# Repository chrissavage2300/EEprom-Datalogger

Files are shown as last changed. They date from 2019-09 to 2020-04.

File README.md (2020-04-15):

The purpose of this project is to take in readings from various sensors (Light and Temperature) and store them in a EEprom. I re-started this project because I wanted to log temperature and the amount of light in a particular area for a garden. I wanted it to be small and not be a full fledged datalogger with a transmitter.

Features:
* Capacitor Backup that will last at the very least 12 hours (During the night)
* Solar charging during the day
* Integrated ORing power circuit so it will charge the capacitor and run the supporting circuitry
* According to my calculations, for a whole year of 1 reading per hour every day I will need about 8kb of memory per sensor. ADC readings iwll be 8 bits each. In practice there's no need for a 10 bit ADC.
* 32kHz Clock run from Timer 1 for accurate timing
* Why Supercapacitor? Temperature range pretty much. Lithium's only go down to 0C and often times temperatures dip below that. Supercapacitors have a range of -40C to 60C which covers the range of outdoor temperatures. 
* Ive integrated a set of UART commands to feedback the status of the micro. It will always take data, there is no stop.
* Upgraded the caps from 3F to 2x6F for a total of 12F. This should last about 27 hours at 370uA consumption. I never could figure out where that is all going, but its not the micro. It only takes 2-3 minutes to charge in full sun though. So even if its cloudy or the sun panel isnt efficient enough, it only needs a few minutes to charge fully. 
* Note: When sending UART commands a "1" has to come before it, so "1a" to read the EEprom. This is by design to wake up the micro so it can recieve stuff properly.
* The Micro Keeps track of the current EEprom address. One issue is that if power ever does get low enough, it will lose the current EEprom address and therefore return to 0 and then all data will be lost. I could have dumped in the EEprom address into the micro's own EEprom and store it if power gets low, but I chose not to.

Commands are as follows:
* "1a" = Read EEprom
* "1E" = Erase EEprom
* "1q" = Status, spits out Seconds,Minutes,MaxAddress,Temp,Solar in that order
* "1t" = current time in MM:SS. Does not track hours passed. 
* "1m" = Used Memory Locations. Shows how much memory has been written to. Currently, two bytes get written into the EEprom

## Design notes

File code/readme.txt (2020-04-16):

I2C_EEProm_Datalogger_2020_04_16_A is the latest file

Changes:
4/16/2020-Added in total run time.

4/15/2020- Final Version.Ready for depolyment. 

4/11/2020-RX needs to be tied high in order to avoid triggering The recieve Interrupt

1/26/2020- Temperature Sensor Works. Units are °C

1/19/2020-Board works and turns RB 7 on and off

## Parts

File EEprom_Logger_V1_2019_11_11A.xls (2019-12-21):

"Part" | "Value" | "Device" | "Package"
"C1" | "10pF" | "CAP1206" | "1206" | ‎311-1150-1-ND‎ (https://www.digikey.com/product-detail/en/CC1206JRNPO9BN100/311-1150-1-ND/303060/?itemSeq=309446462)
"C2" | "10pf" | "CAP1206" | "1206" | ‎311-1150-1-ND‎ (https://www.digikey.com/product-detail/en/CC1206JRNPO9BN100/311-1150-1-ND/303060/?itemSeq=309446462)
"C3" | "22uF" | "CAP1206" | "1206" | ‎587-3397-1-ND‎ (https://www.digikey.com/product-detail/en/JMK316ABJ226KL-T/587-3397-1-ND/4157510/?itemSeq=309446346)
"C4" | "22uF" | "CAP1206" | "1206" | ‎587-3397-1-ND‎ (https://www.digikey.com/product-detail/en/JMK316ABJ226KL-T/587-3397-1-ND/4157510/?itemSeq=309446346)
"C5" | "3F | 2.7V" | "CPOL-USE3.5-8" | 283-4197-ND‎ (https://www.digikey.com/product-detail/en/HV0820-2R7305-R/283-4197-ND/3878077/?itemSeq=304842971)
"C6" | "3F | 2.7V" | "CPOL-USE3.5-8" | 283-4197-ND‎ (https://www.digikey.com/product-detail/en/HV0820-2R7305-R/283-4197-ND/3878077/?itemSeq=304842971)
"D1" | LM4040BIM3-2.0/NOPBCT-ND | "V-REFERENCESMD" | "SOT23-3" | ‎LM4040BIM3X-2.5/NOPBCT-ND‎ (https://www.digikey.com/product-detail/en/LM4040BIM3X-2.5%2FNOPB/LM4040BIM3X-2.5%2FNOPBCT-ND/3527237/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)
"IC1" | " AP2138N-3.3TRG1" | "XC63FPM" | "SOT23" | AP2138N-3.3TRG1DICT-ND‎ (https://www.digikey.com/product-detail/en/AP2138N-3.3TRG1/AP2138N-3.3TRG1DICT-ND/4505282/?itemSeq=304696187)
"IC2" | "PIC18F13K22SOP" | "PIC18F13K22SOP" | "SOP20W" | PIC18LF13K22-I/SO-ND‎ (https://www.digikey.com/product-detail/en/PIC18LF13K22-I%2FSO/PIC18LF13K22-I%2FSO-ND/2125565/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)
"IC3" | "MIC94090" | "MIC94090" | "SC-70" | 576-3484-1-ND‎ (https://www.digikey.com/product-detail/en/MIC94090YC6-TR/576-3484-1-ND/2062481/?itemSeq=309193336)
"IC4" | "MCP1700T-2702E/TT " | "XC63FPM" | "SOT23" | MCP1700T-2702E/TTCT-ND‎ (https://www.digikey.com/product-detail/en/MCP1700T-2702E%2FTT/MCP1700T-2702E%2FTTCT-ND/9642903/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)
"IC5" | "24LC64BSN" | "24LC64BSN" | "SO-08" | ‎24LC64-I/SN-ND‎ (https://www.digikey.com/product-detail/en/24LC64-I%2FSN/24LC64-I%2FSN-ND/273428/?itemSeq=309194840)
"IC6" | "TPS613221ADBVR" | "TPS61322" | "DBV5-L" | 296-50502-1-ND‎ (https://www.digikey.com/product-detail/en/TPS613221ADBVR/296-50502-1-ND/9685641/?itemSeq=304964084)
"IC7" | "LM66100" | "LM66100" | "SC70-6" | 296-53540-6-ND‎ (https://www.digikey.com/product-detail/en/LM66100DCKT/296-53540-6-ND/10273340/?itemSeq=305014552)
"IC8" | "LM66100" | "LM66100" | "SC70-6" | 296-53540-6-ND‎ (https://www.digikey.com/product-detail/en/LM66100DCKT/296-53540-6-ND/10273340/?itemSeq=305014552)
"JP1" | "ICSP" | "M05PTH" | "1X05" | ‎2057-PH1-05-UA-ND‎ (https://www.digikey.com/product-detail/en/PH1-05-UA/2057-PH1-05-UA-ND/9830343/?itemSeq=309668104)
"JP3" | "" | "M02LOCK" | "1X02_LOCK" | ‎S1012EC-02-ND‎ (https://www.digikey.com/product-detail/en/PREC002SAAN-RC/S1012EC-02-ND/2774852/?itemSeq=309668382)
"JP7" | "Vsolar" | "CONN_02POLAR_LOCK" | "MOLEX-1X2_LOCK@1" | ‎A98333-ND‎ (https://www.digikey.com/product-detail/en/282834-2/A98333-ND/1150135/?itemSeq=309668994)
"L1" | "4.7uH" | "INDUCTOR1210" | "1210" | ‎587-1624-1-ND‎ (https://www.digikey.com/product-detail/en/CBC3225T4R7MR/587-1624-1-ND/1008239/?itemSeq=309446164)
"R1" | "1k" | "RESISTOR1206" | "1206" | ‎311-1.00KFRCT-ND‎ (https://www.digikey.com/product-detail/en/RC1206FR-071KL/311-1.00KFRCT-ND/731334/?itemSeq=309259054) | stock
"R2" | "4.7k" | "RESISTOR1206" | "1206" | 311-4.70KFRCT-ND‎ (https://www.digikey.com/product-detail/en/RC1206FR-074K7L/311-4.70KFRCT-ND/731834/?itemSeq=309259149)
"R3" | "4.7k" | "RESISTOR1206" | "1206" | 311-4.70KFRCT-ND‎ (https://www.digikey.com/product-detail/en/RC1206FR-074K7L/311-4.70KFRCT-ND/731834/?itemSeq=309259149)
"R4" | "1k" | "RESISTOR1206" | "1206" | ‎311-1.00KFRCT-ND‎ (https://www.digikey.com/product-detail/en/RC1206FR-071KL/311-1.00KFRCT-ND/731334/?itemSeq=309259054) | stock
"R5" | "TBD" | "RESISTOR1206" | "1206" | ‎311-0.0ERCT-ND‎ (https://www.digikey.com/product-detail/en/RC1206JR-070RL/311-0.0ERCT-ND/732131/?itemSeq=309669297)
"R6" | "TBD" | "RESISTOR1206" | "1206"
"R7" | "TBD" | "RESISTOR1206" | "1206" | ‎311-0.0ERCT-ND‎ (https://www.digikey.com/product-detail/en/RC1206JR-070RL/311-0.0ERCT-ND/732131/?itemSeq=309669297)
"R8" | "TBD" | "RESISTOR1206" | "1206"
"R9" | "50" | "RESISTOR1206" | "1206" | ‎311-51.0FRCT-ND‎ (https://www.digikey.com/product-detail/en/RC1206FR-0751RL/311-51.0FRCT-ND/731920/?itemSeq=309445787)
"R10" | "50" | "RESISTOR1206" | "1206" | ‎311-51.0FRCT-ND‎ (https://www.digikey.com/product-detail/en/RC1206FR-0751RL/311-51.0FRCT-ND/731920/?itemSeq=309445787)
"TS1" | "MCP9700-E/TO" | "MCP9700-E/TO" | "TO-92-AMMO" | ‎MCP9700-E/TO-ND‎ (https://www.digikey.com/product-detail/en/MCP9700-E%2FTO/MCP9700-E%2FTO-ND/1212509/?itemSeq=309195025)
"Y1" | "32kHz" | "CRYSTALTC26V" | "TC26V" | ‎728-1001-ND‎ (https://www.digikey.com/product-detail/en/VT200F-12.5PF20PPM/728-1001-ND/1626716/?itemSeq=309446886) | stock

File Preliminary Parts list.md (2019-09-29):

# EEprom-Datalogger
A remote datalogger that uses an EEprom to store data over time. 
Super Cap:  1572-1771-ND

https://www.ti.com/lit/ds/symlink/tps63031.pdf

http://www.ti.com/product/TPS63031

http://www.ti.com/product/TPS62203

https://www.digikey.com/product-detail/en/richtek-usa-inc/RT6150AGQW/1028-1259-1-ND/4733181

https://www.digikey.com/product-detail/en/texas-instruments/TPS63031DSKR/296-39461-1-ND/5143409

https://electronics.stackexchange.com/questions/240329/using-supercapacitor-as-backup-for-mcu

http://www.ti.com/lit/ug/slva726/slva726.pdf

http://www.ti.com/lit/ds/symlink/tps63020.pdf

 TPS613222ADBVR
 
https://www.digikey.com/product-detail/en/texas-instruments/TPS613222ADBVR/296-50503-1-ND/9685642

http://www.ti.com/lit/ds/symlink/tps61322.pdf

MCP1700T-2702E/TTCT-ND‎
https://www.digikey.com/product-detail/en/MCP1700T-2702E%2fTT/MCP1700T-2702E%2fTTCT-ND/9642903/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

LM66100DCKT

http://www.ti.com/lit/ds/symlink/lm66100.pdf

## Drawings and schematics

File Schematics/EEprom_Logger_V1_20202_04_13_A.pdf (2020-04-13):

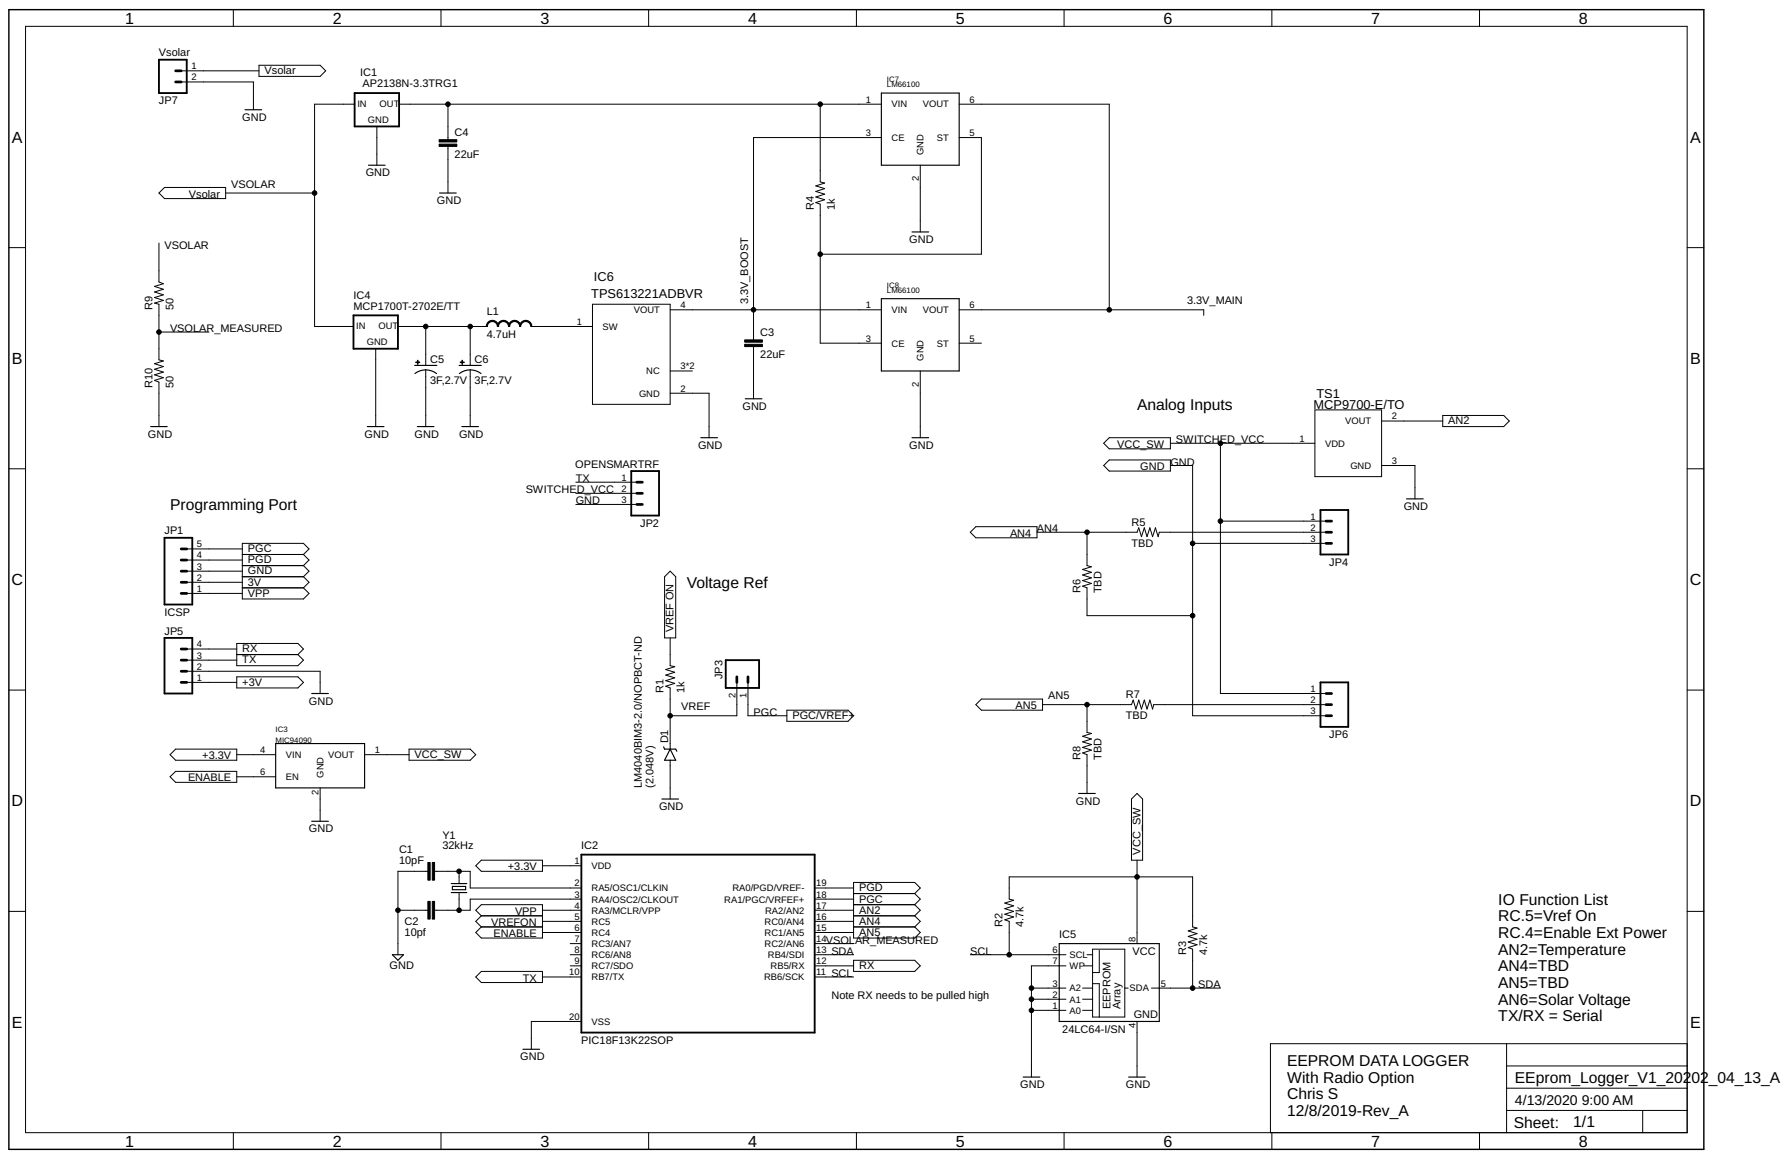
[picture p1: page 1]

IO Function List RC.5=Vref On RC.4=Enable Ext Power AN2=Temperature AN4=TBD

AN6=Solar Voltage TX/RX = Serial Note RX needs to be pulled high

EEPROM DATA LOGGER With Radio Option Chris S 12/8/2019-Rev_A

Sheet: 1/1

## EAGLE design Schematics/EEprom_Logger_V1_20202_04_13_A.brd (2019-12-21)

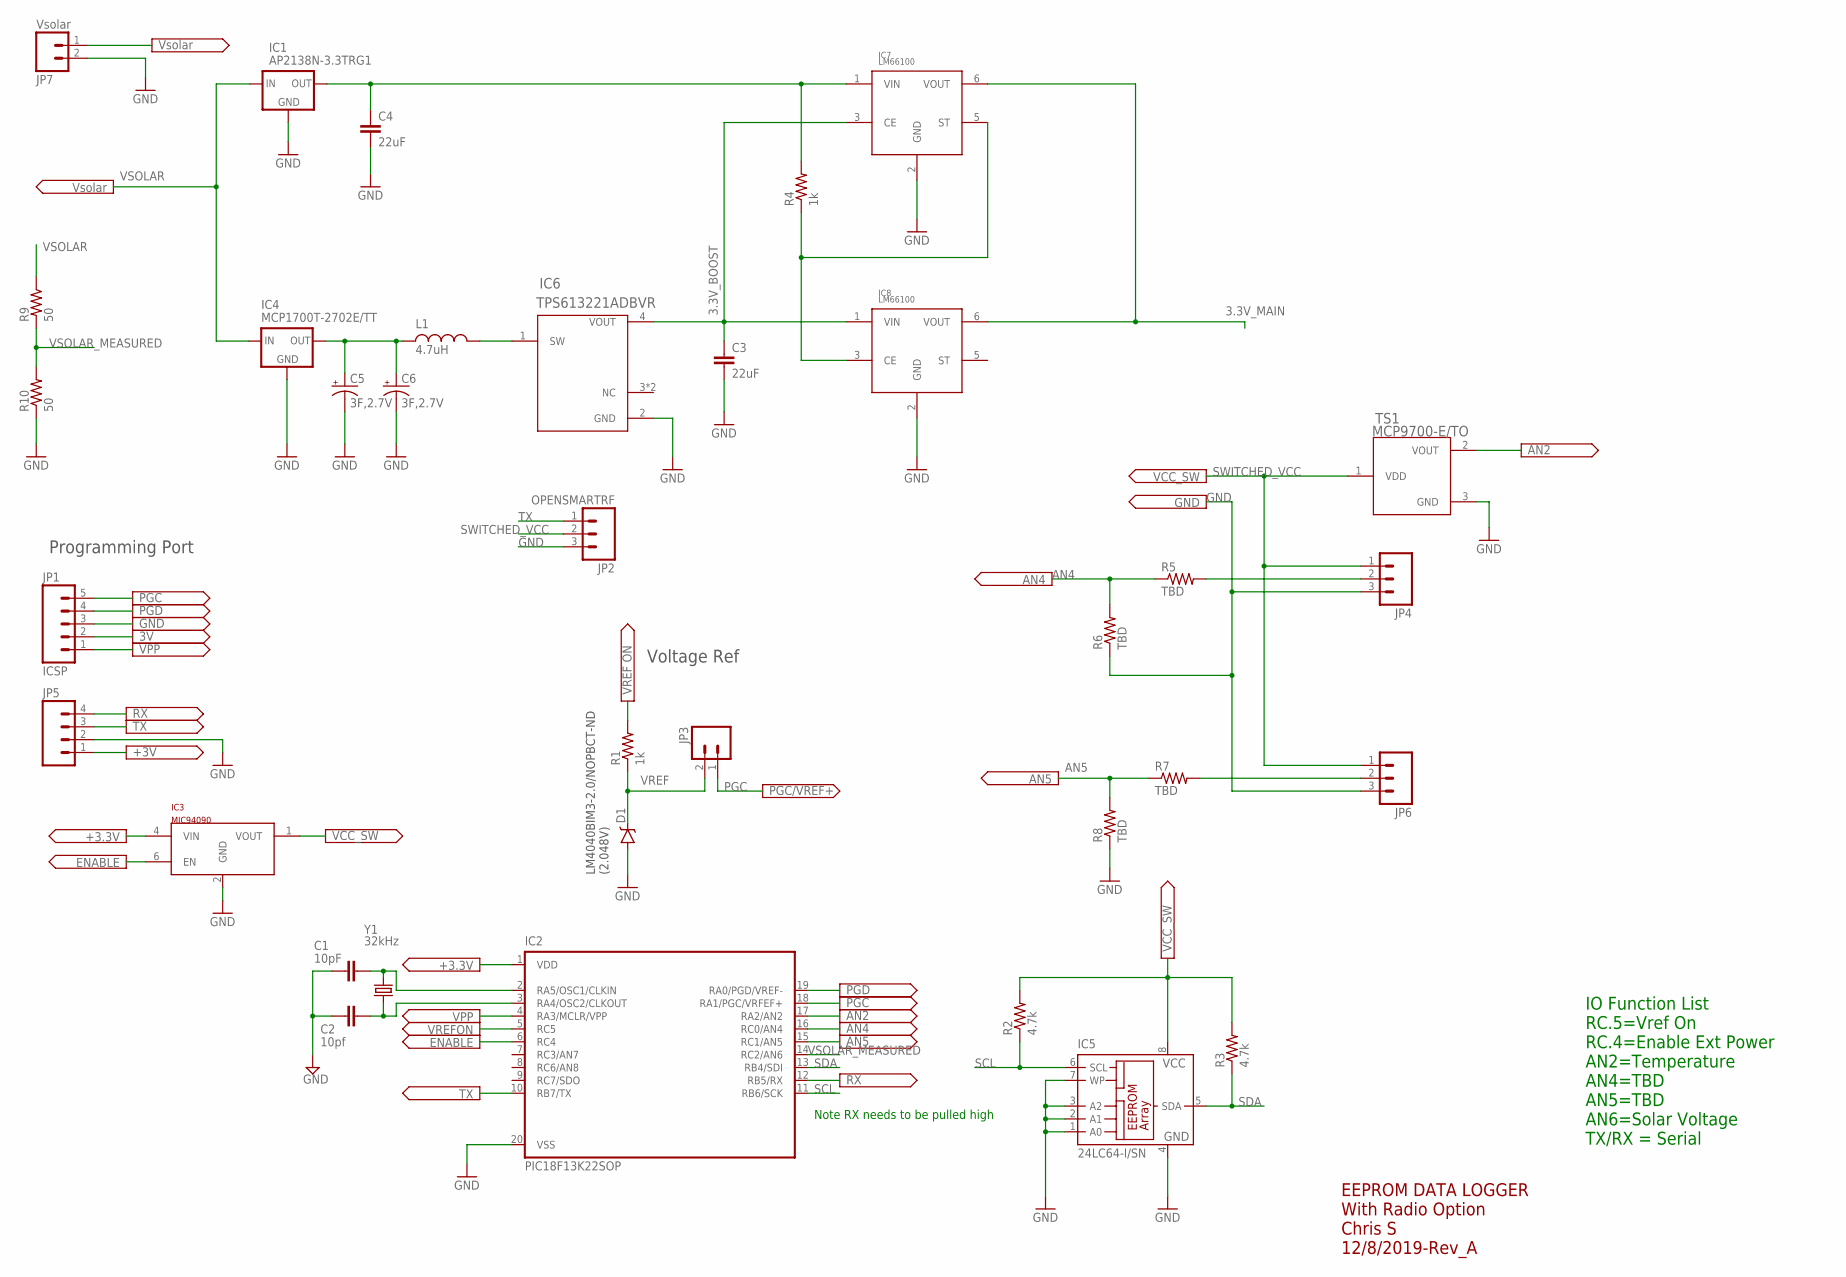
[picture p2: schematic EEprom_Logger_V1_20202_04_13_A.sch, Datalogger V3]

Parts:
C1: 10pF; 1206
C2: 10pf; 1206
C3, C4: 22uF; 1206
C5, C6: 3F,2.7V; E3,5-8
D1: V-REFERENCESMD; SOT23-3
IC1: AP2138N-3.3TRG1; SOT23
IC2: PIC18F13K22SOP; SOP20W
IC3: MIC94090; SC-70
IC4: MCP1700T-2702E/TT; SOT23
IC5: 24LC64-I/SN; SO-08
IC6: TPS613221ADBVR; DBV5-L
IC7, IC8: LM66100; SC70-6
JP1: ICSP; 1X05
JP2: OPENSMARTRF; 1X03_LONGPADS@1
JP3: M02LOCK; 1X02_LOCK
JP4, JP6: 455-1750-1-ND; 1X03
JP5: M04PTH; 1X04
JP7: Vsolar; MOLEX-1X2_LOCK@1
L1: 4.7uH; 1210
R1, R4: 1k; 1206
R2, R3: 4.7k; 1206
R5, R6, R7, R8: TBD; 1206
R9, R10: 50; 1206
TS1: MCP9700-E/TO; TO-92-AMMO
Y1: 32kHz; TC26V

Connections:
3.3V_BOOST: C3.2, IC6.4 (VOUT), IC7.3 (CE), IC8.1 (VIN)
3.3V_MAIN: IC2.1 (VDD), IC3.4 (VIN), IC7.6 (VOUT), IC8.6 (VOUT), JP1.2, JP5.1
AN2: IC2.17 (RA2/AN2), TS1.2 (VOUT)
AN4: IC2.16 (RC0/AN4), R5.1, R6.2
AN5: IC2.15 (RC1/AN5), R7.1, R8.2
ENABLE: IC2.6 (RC4), IC3.6 (EN)
GND: C1.2, C2.2, C3.1, C4.1, C5.-, C6.-, D1.2 (A), IC1.1 (GND), IC2.20 (VSS), IC3.2 (GND), IC4.1 (GND), IC5.1 (A0), IC5.2 (A1), IC5.3 (A2), IC5.4 (GND), IC5.7 (WP), IC6.2 (GND), IC7.2 (GND), IC8.2 (GND), JP1.3, JP2.3, JP4.3, JP5.2, JP6.3, JP7.2, R6.1, R8.1, R10.1, TS1.3 (GND)
unnamed: C1.1, IC2.2 (RA5/OSC1/CLKIN), Y1.2
unnamed: C2.1, IC2.3 (RA4/OSC2/CLKOUT), Y1.1
unnamed: C4.2, IC1.2 (OUT), IC7.1 (VIN), R4.2
unnamed: C5.+, C6.+, IC4.2 (OUT), L1.1
unnamed: IC7.5 (ST), IC8.3 (CE), R4.1
unnamed: JP4.2, R5.2
unnamed: IC6.1 (SW), L1.2
unnamed: JP6.2, R7.2
PGC: IC2.18 (RA1/PGC/VRFEF+), JP1.5, JP3.1
PGD: IC2.19 (RA0/PGD/VREF-), JP1.4
RX: IC2.12 (RB5/RX), JP5.4
SCL: IC2.11 (RB6/SCK), IC5.6 (SCL), R2.1
SDA: IC2.13 (RB4/SDI), IC5.5 (SDA), R3.1
SWITCHED_VCC: IC3.1 (VOUT), IC5.8 (VCC), JP2.2, JP4.1, JP6.1, R2.2, R3.2, TS1.1 (VDD)
TX: IC2.10 (RB7/TX), JP2.1, JP5.3
VPP: IC2.4 (RA3/MCLR/VPP), JP1.1
VREF: D1.1 (C), JP3.2, R1.1
VREFON: IC2.5 (RC5), R1.2
VSOLAR: IC1.3 (IN), IC4.3 (IN), JP7.1, R9.1
VSOLAR_MEASURED: IC2.14 (RC2/AN6), R9.2, R10.2

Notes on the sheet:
LM4040BIM3-2.0/NOPBCT-ND (2.048V)
Voltage Ref
Programming Port
EEPROM DATA LOGGER With Radio Option Chris S 12/8/2019-Rev_A
IO Function List RC.5=Vref On RC.4=Enable Ext Power AN2=Temperature AN4=TBD AN5=TBD AN6=Solar Voltage TX/RX = Serial
Note RX needs to be pulled high

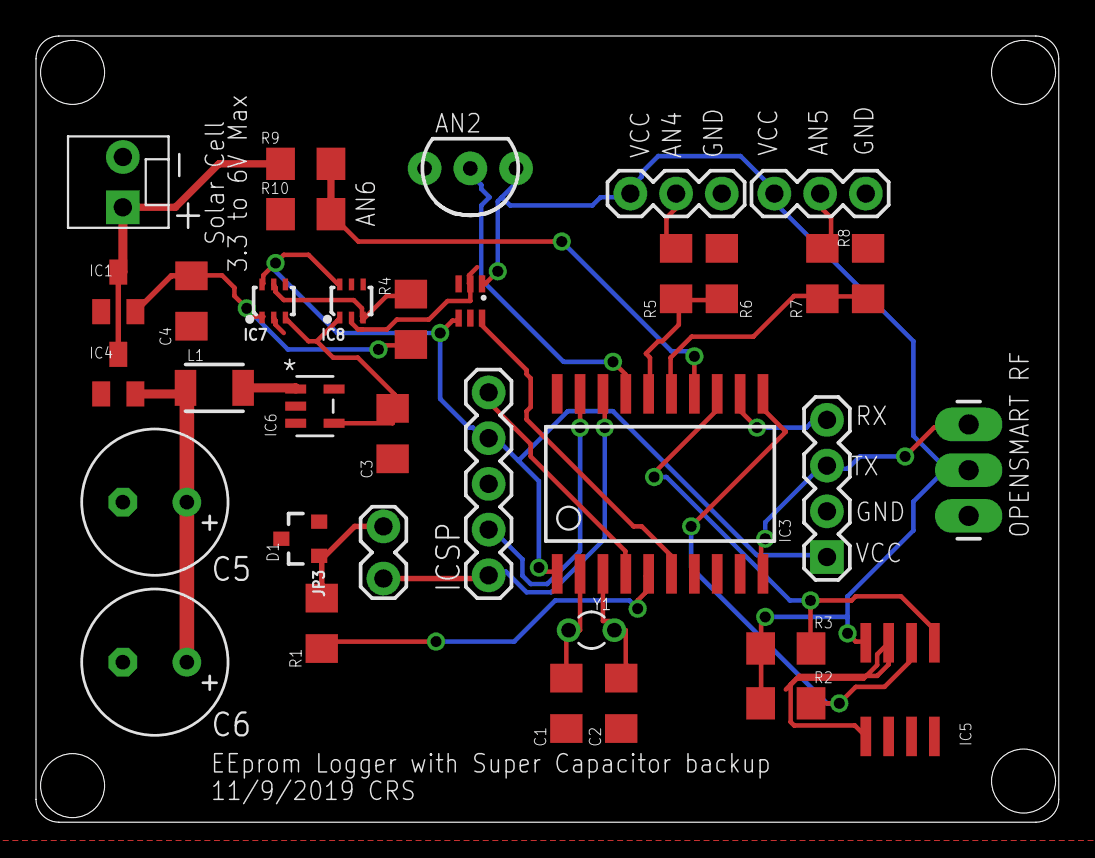
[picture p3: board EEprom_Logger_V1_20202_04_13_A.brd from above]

Board: 2 copper layers, 56.8 x 43.7 mm, 35 parts (0 on the bottom side), 27 nets.

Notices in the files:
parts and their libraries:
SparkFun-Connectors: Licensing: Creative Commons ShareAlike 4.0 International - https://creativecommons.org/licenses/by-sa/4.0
